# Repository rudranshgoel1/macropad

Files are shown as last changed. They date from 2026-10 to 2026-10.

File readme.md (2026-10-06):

# macropad
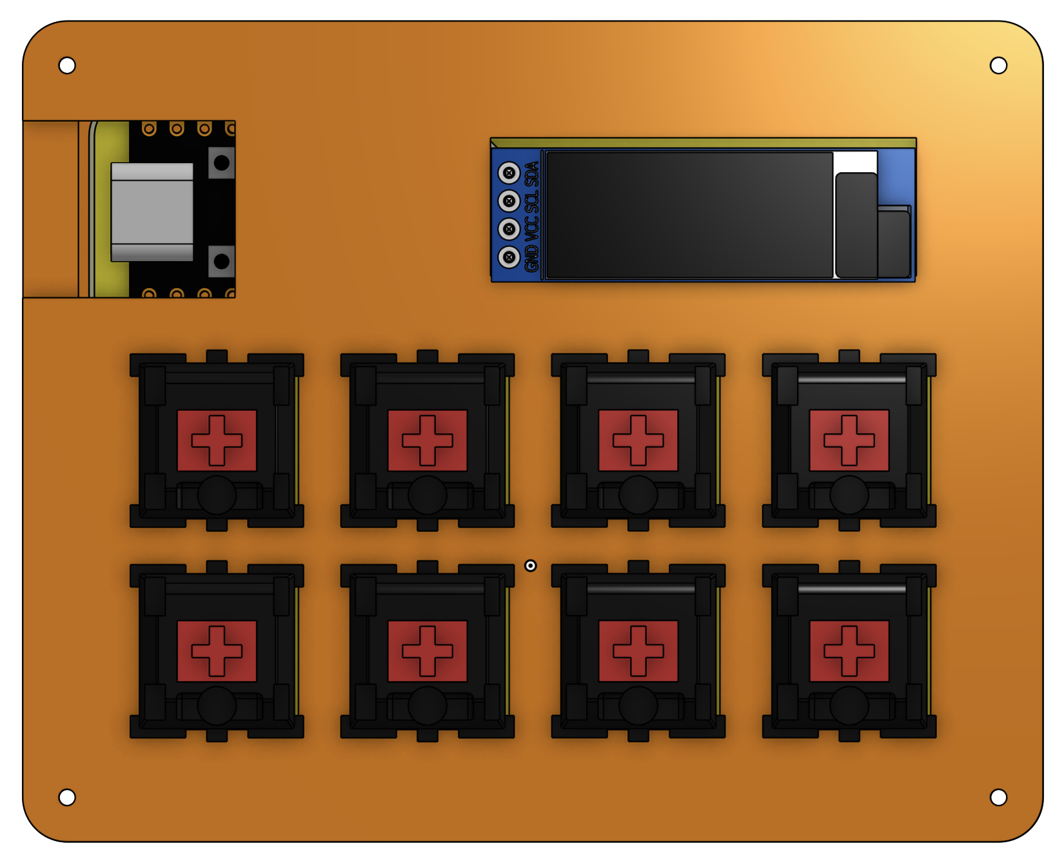
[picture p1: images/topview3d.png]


### Why did I make it?
bcz i need more hardware projects in my portfolio and also because it seemed like a fun hardware project which was kinda beginner friendly.

### What was the hardest part about this ?
honestly speaking, CAD.

Features:

- 8 Remappable Key Matrix for anything!
- ESP32C3 SuperMini as the main brain
- Custom PCB Art (really cool)
- Custom case

### Schematic
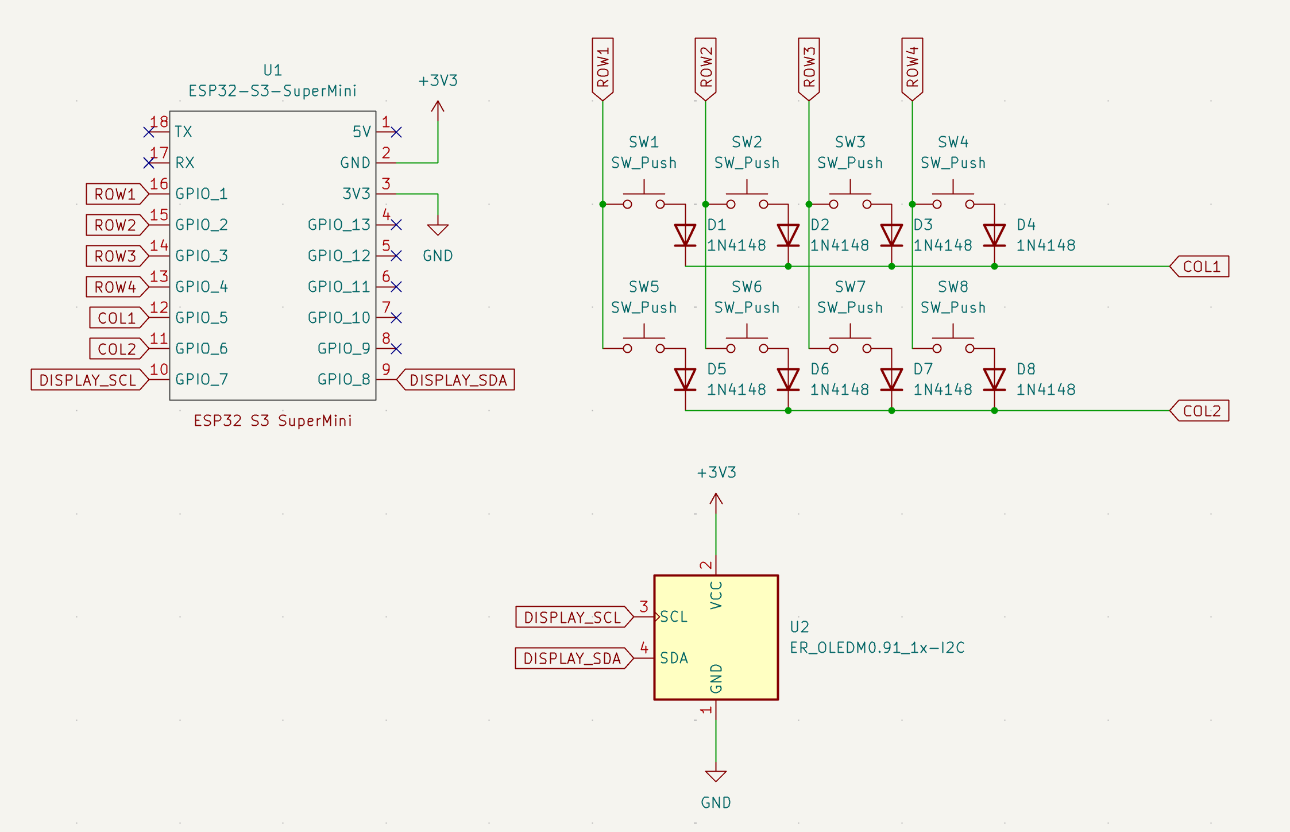
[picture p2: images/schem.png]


### PCB 
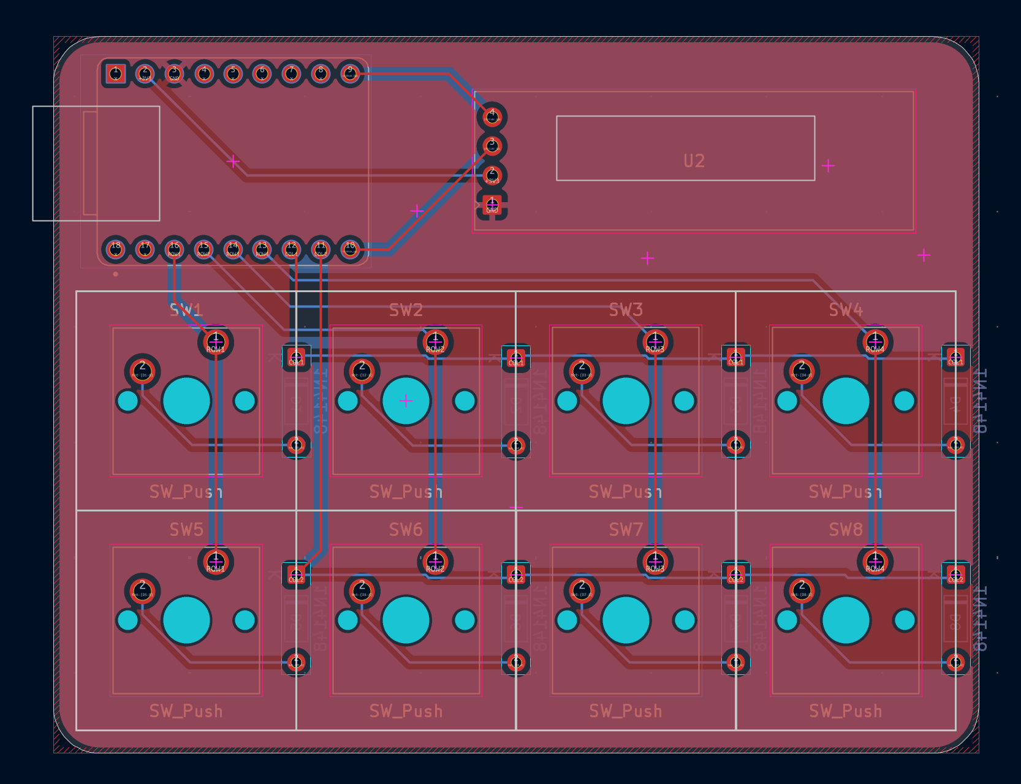
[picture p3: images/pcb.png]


### Case

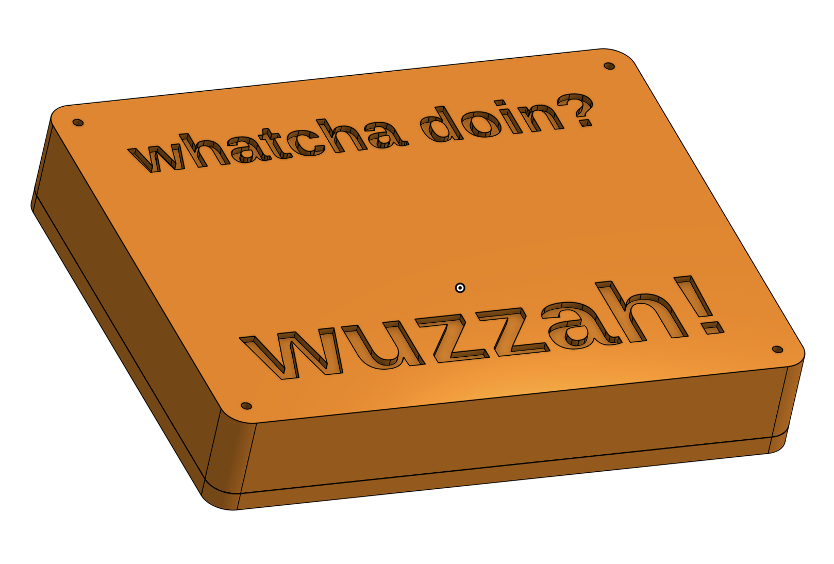
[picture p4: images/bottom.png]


### 3D view of all parts 

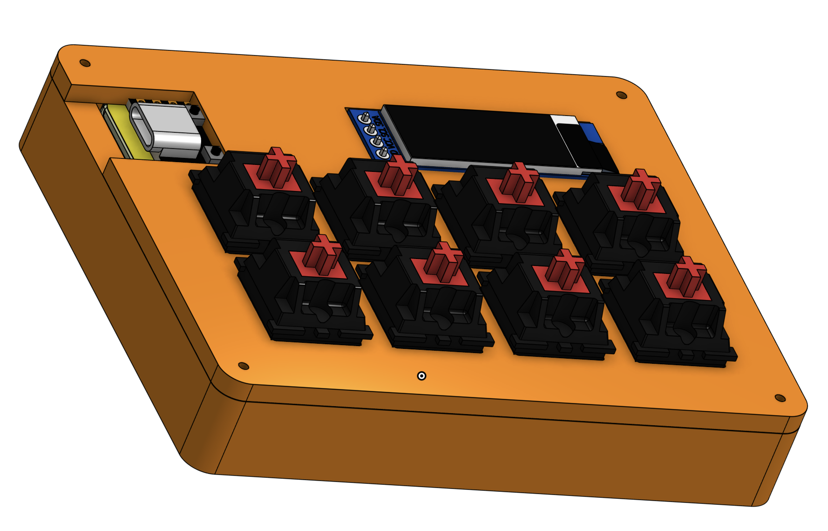
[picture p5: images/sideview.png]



link to full 3d thing-
https://cad.onshape.com/documents/f3f4d199ef23d310b3ca664c/w/34908b541132c21f4c70cc87/e/ea0e0a44c36532055dd3e013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

## BOM

[BOM](BOM.csv)
|Name |Purpose |Quantity|Total Cost (USD)|Link |Distributor |
|---|---|---|---|---|---|
|ESP32-S3 SuperMini |Main MCU |1 |7.4 |https://www.amazon.in/gp/product/B0H8YMNKHL |Amazon |
|Switches for Transmitter |Switches for controlling the car|8 |0 |SELF SOURCED |SELF SOURCED |
|Keycaps for the switches |Keycaps of the switches |8 |0 |SELF SOURCED |SELF SOURCED |
|0.91 inch display |Display |1 |2.2 |https://robu.in/product/0-91-inch-128x32-i2c-iic-serial-blue-oled-lcd-display-module/|Robu |
|Case 3D Printed |Case for the entire macropad |1 |0 |Printing Legion |Printing Legion|
|PCB of Transmitter AND Receiver|Main PCBs |5 |13.82 |https://jlcpcb.com/ |JLPCB |
| | | | | | |
| | | |23.42 | | |

## Total Pricing

Final Price comes out to be 5,430 INR ($57.1) [ SHIPPING INCLUDED ]

The pricing might slightly vary due to flash sales, and dollar market trends.

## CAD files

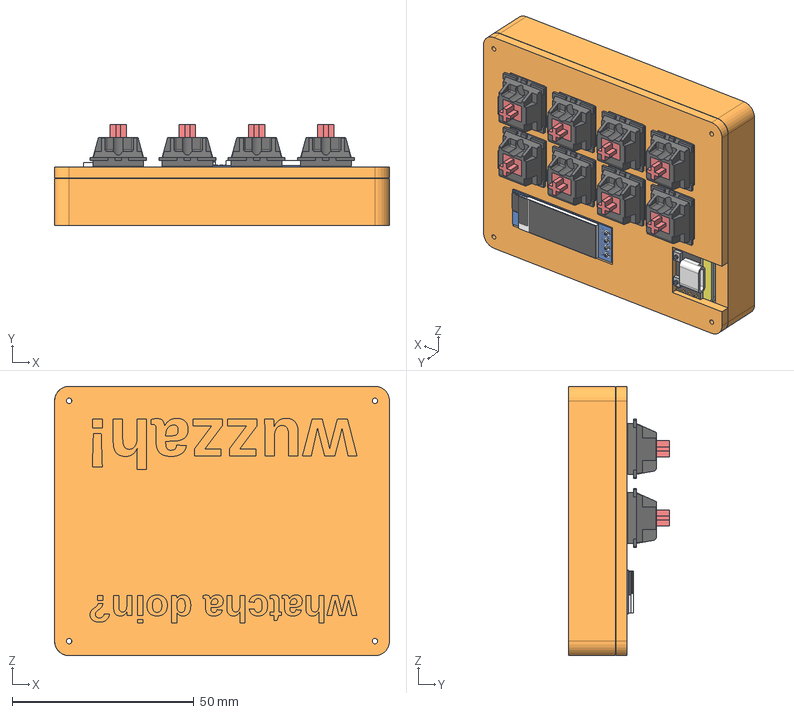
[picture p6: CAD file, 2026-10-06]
Production/CAD/Full Assembly.step
92.2 x 27.9 x 74.2 mm
macropad-unsaved-export-lRRnL9_pad x 162
Pin Header 4 x 1 TH 2.54mm Pitch x 8
RESC-0603_7 x 3
RESC-0603_12 x 3
D_DO-35_SOD27_P7.62mm_Horizontal_7 x 2
macropad-unsaved-export-lRRnL9_copper x 29
RESC-0603_10 x 3
RESC-0603_9 x 3
D_DO-35_SOD27_P7.62mm_Horizontal_5 x 2
RESC-0603_5 x 3
2SD0601A x 4
RESC-0603_8 x 3
RESC-0603_11 x 3
RESC-0603_2 x 3
D_DO-35_SOD27_P7.62mm_Horizontal x 2
RESC-0603_4 x 3
RESC-0603 x 3
macropad-unsaved-export-lRRnL9_PCB
RESC-0603_3 x 3
D_DO-35_SOD27_P7.62mm_Horizontal_2 x 2
RESC-0603_6 x 3
D_DO-35_SOD27_P7.62mm_Horizontal_6 x 2
D_DO-35_SOD27_P7.62mm_Horizontal_4 x 2
D_DO-35_SOD27_P7.62mm_Horizontal_1 x 2
D_DO-35_SOD27_P7.62mm_Horizontal_3 x 2
RESC-0603_1 x 3
macropad-unsaved-export-lRRnL9_silkscreen
root
OLED_0.91_128x32

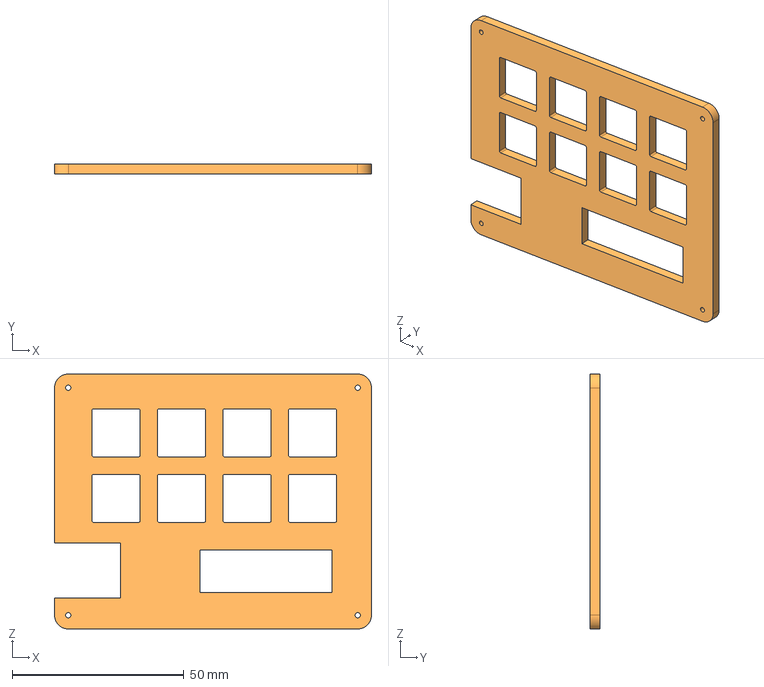
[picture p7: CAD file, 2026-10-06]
Production/CAD/Top Plate (1).step
92.2 x 3.00 x 74.2 mm

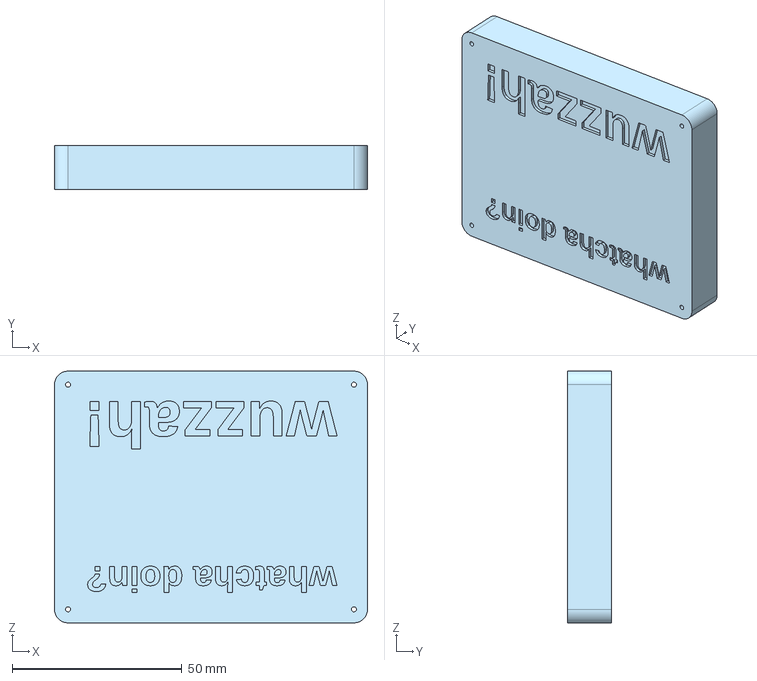
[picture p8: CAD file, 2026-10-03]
Production/CAD/Bottom Part.step
92.2 x 13.0 x 74.2 mm

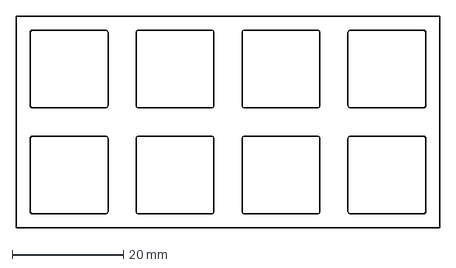
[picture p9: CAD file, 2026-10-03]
Production/CAD/plate-2026-10-03T18_55_53.838Z.dxf
76.2 x 38.1 mm

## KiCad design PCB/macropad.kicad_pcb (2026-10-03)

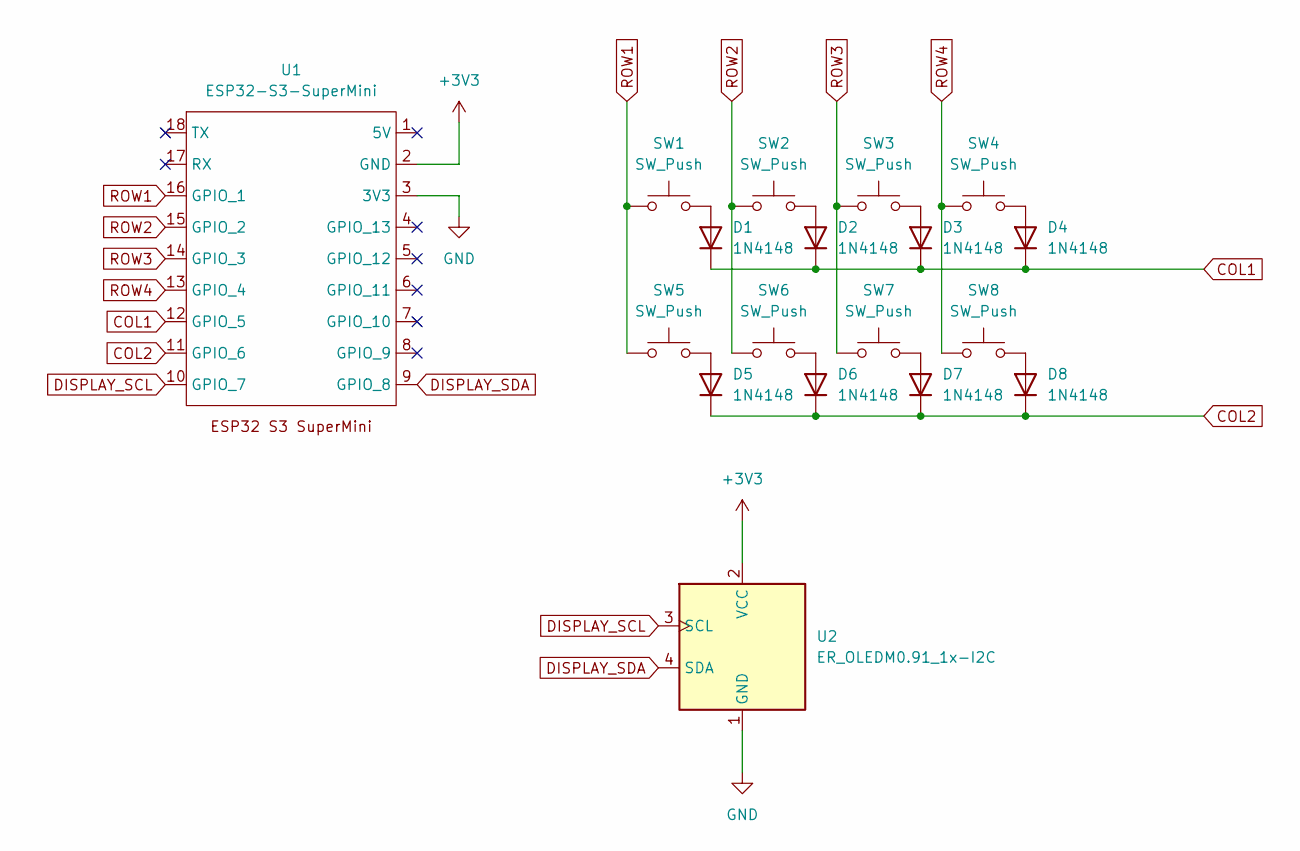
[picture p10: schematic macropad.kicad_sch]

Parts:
D1, D2, D3, D4, D5, D6, D7, D8: 1N4148; D_DO-35_SOD27_P7.62mm_Horizontal
SW1, SW2, SW3, SW4, SW5, SW6, SW7, SW8: SW_Push; SW_Cherry_MX_1.00u_PCB
U1: ESP32-S3-SuperMini
U2: ER_OLEDM0.91_1x-I2C

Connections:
+3V3: U1.2 (GND), U2.2 (VCC)
COL1: D1.1 (K), D2.1 (K), D3.1 (K), D4.1 (K), U1.12 (GPIO_5)
COL2: D5.1 (K), D6.1 (K), D7.1 (K), D8.1 (K), U1.11 (GPIO_6)
DISPLAY_SCL: U1.10 (GPIO_7), U2.3 (SCL)
DISPLAY_SDA: U1.9 (GPIO_8), U2.4 (SDA)
GND: U1.3 (3V3), U2.1 (GND)
unnamed: D1.2 (A), SW1.2
unnamed: D2.2 (A), SW2.2
unnamed: D3.2 (A), SW3.2
unnamed: D4.2 (A), SW4.2
unnamed: D5.2 (A), SW5.2
unnamed: D6.2 (A), SW6.2
unnamed: D7.2 (A), SW7.2
unnamed: D8.2 (A), SW8.2
ROW1: SW1.1, SW5.1, U1.16 (GPIO_1)
ROW2: SW2.1, SW6.1, U1.15 (GPIO_2)
ROW3: SW3.1, SW7.1, U1.14 (GPIO_3)
ROW4: SW4.1, SW8.1, U1.13 (GPIO_4)

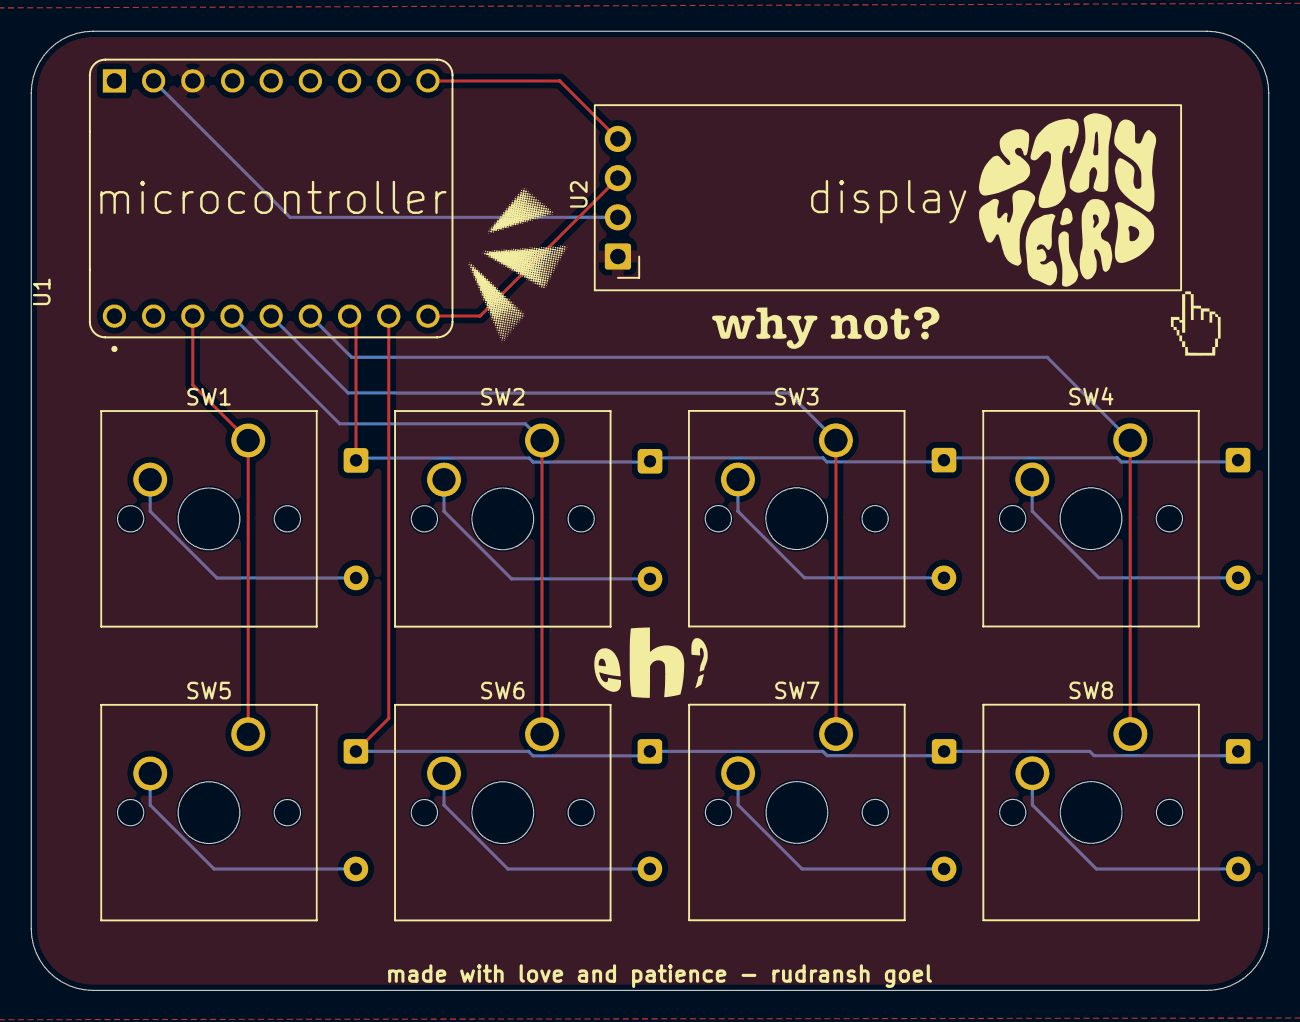
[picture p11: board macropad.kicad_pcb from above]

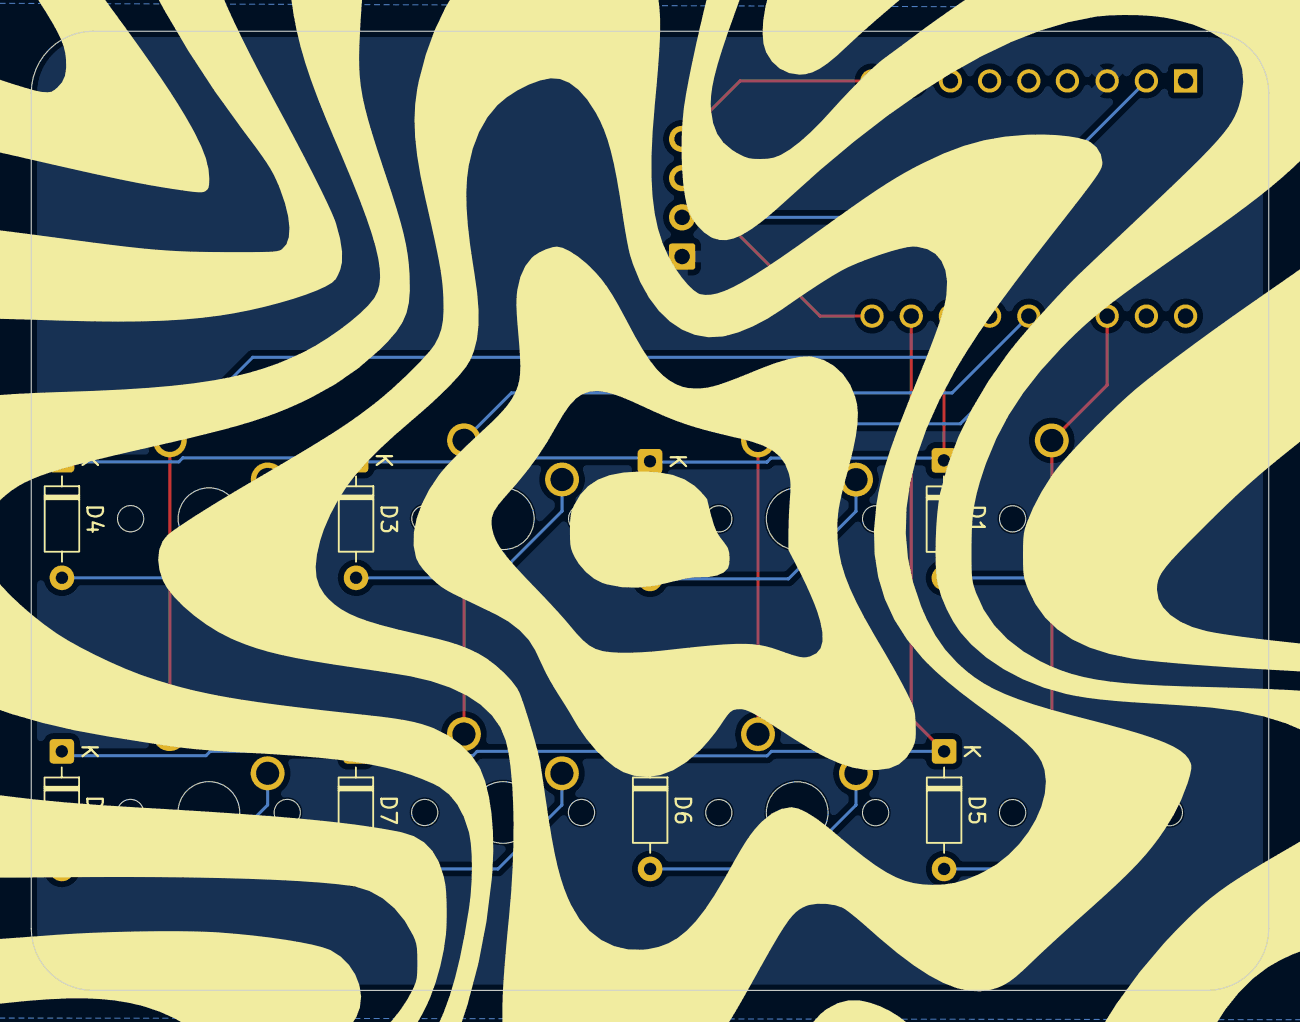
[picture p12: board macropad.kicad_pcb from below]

Board: 2 copper layers, 80.2 x 62.2 mm, 18 parts (8 on the bottom side), 18 nets.

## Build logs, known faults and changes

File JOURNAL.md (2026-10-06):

---
title: "macropad"
author: "stolen_username"
created_at: "2026-10-02"
---

# 2026-10-07: completed github repo + firmware

**Total time spent: 0 minutes**

# what did i do?
- completed the github repo
- time was tracked through hackatime (explains the 0 minute time spent)



# 2026-10-07: BOM

**Total time spent: 8 minutes**

# what did i do?
- added BOM
- found out the pcb costs $13 and total is approx $25



# 2026-10-07: finished CAD

**Total time spent: 35 minutes**

# what did i do?
- i asked my friend and found out what i was doing wrong
- fixed the top plate
- added it in the assembly and the repo
- made holes for oled, switches and the usb slot





# 2026-10-03: started CAD

**Total time spent: 1 hour 16 minutes**

# what did i do?
- started with CAD in onshape
- it was really hard and time consuming coz i really hate cad and don't wanna learn it fully
- wrote "watcha doin?" in the back of the case
- added 4 holes for m3 screws in the corners
- started with the top plate
- then i started to struggle a lot because i really don't know what i was doing wrongly
- exported the pcb and imported it in the assembly in onshape



# 2026-10-02: started with the pcb

**Total time spent: 1 hour 11 minutes**

# what did i do?
- started with pcb
- layout
- removed buzzer and gps coz its too much tech for a mere macropad :sob:
- put diodes on each switch
- rounded the corners by the arc thing in kicad
- did routing
- poured gnd copper
- setup 3d models for each part
- found some silkscreen components on pinterest
- put up some silkscreen



# 2026-10-02: started the schematic

**Total time spent: 45 minutes**

# why?
- coz i have made multiple projects but not a macropad and having it would be convinient that i can just connect it and run small tasks easily

# what did i do?
- started the schematic
- chose esp32 s3 supermini as the mcu (love this mcu)
- the matrix is a 2x4 layout
- added a display (0.91 oled) so that i can display stuff like weather or smth
- added neo6dm for tracking purposes
- added buzzer for fun



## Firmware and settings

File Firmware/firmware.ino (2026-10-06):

// ESP32-S3 SuperMini — 2x4 Button Matrix
// 2 Rows × 4 Columns = 8 buttons

const int ROWS = 2;
const int COLS = 4;

// Change these to match your PCB wiring
const int rowPins[ROWS] = {
  4, 5
};

const int colPins[COLS] = {
  6, 7, 8, 9
};

// Button state tracking
bool lastState[ROWS][COLS];
bool currentState[ROWS][COLS];

void setup() {
  Serial.begin(115200);

  // Rows are outputs
  for (int r = 0; r < ROWS; r++) {
    pinMode(rowPins[r], OUTPUT);
    digitalWrite(rowPins[r], HIGH);

    for (int c = 0; c < COLS; c++) {
      lastState[r][c] = false;
      currentState[r][c] = false;
    }
  }

  // Columns are inputs with pull-ups
  for (int c = 0; c < COLS; c++) {
    pinMode(colPins[c], INPUT_PULLUP);
  }

  Serial.println("2x4 Matrix Ready");
}

void loop() {

  for (int r = 0; r < ROWS; r++) {

    // Activate current row
    digitalWrite(rowPins[r], LOW);

    delayMicroseconds(5);

    for (int c = 0; c < COLS; c++) {

      // LOW means button is pressed
      bool pressed = digitalRead(colPins[c]) == LOW;

      currentState[r][c] = pressed;

      // Detect button press
      if (pressed && !lastState[r][c]) {
        Serial.print("Pressed: R");
        Serial.print(r);
        Serial.print(" C");
        Serial.println(c);
      }

      // Detect button release
      if (!pressed && lastState[r][c]) {
        Serial.print("Released: R");
        Serial.print(r);
        Serial.print(" C");
        Serial.println(c);
      }

      lastState[r][c] = pressed;
    }

    // Deactivate row
    digitalWrite(rowPins[r], HIGH);
  }

  delay(5);
}

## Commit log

2026-10-03 add schematic
    [macropad.kicad_sch]
2026-10-03 added pcb from journal 2
    [macropad.kicad_pcb]
2026-10-03 added Bottom CAD files
    [Bottom Part.step, plate-2026-10-03T18_55_53.838Z.dxf]
2026-10-06 added Top Plate CAD
    [Top Plate (1).step]
2026-10-06 added full assembly cad
    [Full Assembly.step]
2026-10-06 fixed repo structure
    [macropad.kicad_pcb, macropad.kicad_sch]
2026-10-06 added gerber and BOM.csv
    [BOM.csv, Bottom Part.step, Full Assembly.step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]
